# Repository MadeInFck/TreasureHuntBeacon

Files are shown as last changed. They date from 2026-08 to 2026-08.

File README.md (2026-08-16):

# Treasure Hunt — Beacon

**English** · [Français](README.fr.md)

BLE beacon specification and DIY build for the **Treasure Hunt** iOS app.

**Frame specification version 1.0.** Beacons and app releases are compatible
within the same major version.

Each hunt step can be marked by an iBeacon. The app ranges nearby beacons to
guide players over the last 30 metres, where GPS alone is too imprecise.

You have two options:

- **Buy** a commercial iBeacon and reconfigure it with the values below.
- **Build** your own from an ESP32 board — see [Build your own](#build-your-own).

---

## Beacon specification

This is the contract. Any beacon that advertises the following frame will be
recognised by the app, regardless of how it was made.

### Identifiers

| Field | Value |
|---|---|
| **UUID** | `A4C27B10-5F3E-4E2A-9D8C-1B6F0E3D7A52` |
| **MAJOR** | Hunt number, `1`–`65535` |
| **MINOR** | `(step << 8) \| battery` — see below |

The UUID is **fixed for the whole project**. It is a namespace, not a device
identifier — Apple's model is one UUID per application, with major and minor
carrying everything else. Do not change it: the app filters on this exact value
and will not see a beacon advertising anything else.

### MINOR encoding

The 16-bit minor carries two fields:

```
 15                    8 7                     0
┌───────────────────────┬───────────────────────┐
│      step (1-255)     │    battery (0-255)    │
└───────────────────────┴───────────────────────┘
```

| Byte | Meaning |
|---|---|
| High | Step number within the hunt, `1`–`255` |
| Low | Battery level, or `0x00` for "no telemetry" |

Battery byte to voltage:

```
voltage_mV = 2500 + (minor & 0xFF) * 10
```

This gives 10 mV steps from 2.50 V to 5.05 V, covering both LiPo and LiFePO4.
`0x00` would decode as 2.50 V — a cell that is already dead — so it is safe to
use as the "no telemetry" sentinel.

Commercial beacons cannot produce this telemetry. Set their minor to
`step << 8` (for example `0x0100` = 256 for step 1) and the app will show the
step with an unknown battery level.

### Radio parameters

| Parameter | Value |
|---|---|
| Advertising interval | 100 ms |
| Advertising flags | `0x04` (BR/EDR not supported) |
| Scan response | Disabled |
| TX power field | **Measured per beacon** — see [calibration](docs/calibration.md) |

The TX power byte is the RSSI an iPhone reads at exactly 1 metre. It is not a
setting you copy — a wrong value makes every distance estimate wrong. Measure it
for each unit, in its final enclosure.

### Full manufacturer data

25 bytes, following the standard `0x1A 0xFF` length and type prefix:

```
4C 00                                            Apple company ID, little-endian
02 15                                            iBeacon subtype + remaining length
A4 C2 7B 10 5F 3E 4E 2A 9D 8C 1B 6F 0E 3D 7A 52  UUID, big-endian
00 01                                            MAJOR = 1, big-endian
01 00                                            MINOR = step 1, no telemetry
C5                                               TX power = -59 dBm
```

Total advertising payload: 3 bytes of flags + 27 bytes of manufacturer data
structure = **30 of the 31 available bytes**. There is no room for a device
name. This is why the firmware calls `BLEDevice::init("")` with an empty string.

### Status LED

Boards with an RGB LED signal their identity at power-up, once:

| Signal | Meaning |
|---|---|
| 1 white flash | booting |
| N violet blinks | hunt number (MAJOR) |
| M blue blinks | step number |

Then a brief pulse every 5 s: **green** alive, **amber** battery low, **red**
battery critical. Red appears nowhere else, so a red pulse always means the
cell needs attention.

Arm the beacon, count violet, count blue, check the pulse colour, close the
box. That is the whole pre-flight check, no phone needed.

---

## Using a commercial beacon

Most commercial iBeacons are reconfigurable through their manufacturer's app.
Set:

- UUID → `A4C27B10-5F3E-4E2A-9D8C-1B6F0E3D7A52`
- Major → your hunt number
- Minor → `step << 8` (step 1 → `256`, step 2 → `512`, step 3 → `768`)
- Advertising interval → 100 ms if adjustable

**Check before buying.** Some low-cost models ship with a factory-locked UUID.
Those cannot be used. The product page must state that the UUID is
user-configurable.

---

## Build your own

| | |
|---|---|
| Firmware | [`firmware/beacon/`](firmware/beacon/) |
| Board choice and wiring | [`hardware/`](hardware/) |
| Enclosure | [`enclosure/`](enclosure/) |
| TX power calibration | [`docs/calibration.md`](docs/calibration.md) |
| Battery and autonomy | [`docs/battery.md`](docs/battery.md) |
| When nothing is detected | [`docs/troubleshooting.md`](docs/troubleshooting.md) |

Minimum to get a beacon on the air: an ESP32 board with BLE, a USB cable, and
the Arduino IDE with the ESP32 core 3.x. Battery and enclosure come later.

---

## Repository layout

```
firmware/
  beacon/          Beacon firmware — flash one per hunt step
  scanner/         Bench scanner — decodes frames, useful for validation
  vbat_probe/      Differential probe — finds a board's VBAT divider
  CONFIGURATION.md Per-beacon settings
hardware/          Boards, wiring diagrams, bill of materials
enclosure/         Parametric OpenSCAD case, ready-made STLs
docs/              Calibration, battery, troubleshooting
```

Code comments are in English only, to keep a single source of truth.
Documentation is available in English and French.

---

## Safety

This project involves lithium cells. Read the warnings in
[`hardware/README.md`](hardware/README.md) before wiring a battery. Sealed
enclosures left in direct sunlight can exceed the safe operating range of both
the board and the cell.

---

## License

MIT — see [LICENSE](LICENSE).

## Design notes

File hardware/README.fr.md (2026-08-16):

# Matériel

[English](README.md) · **Français**

## Choisir une carte

N'importe quel ESP32 doté du BLE émettra correctement. Ce qui les sépare, c'est
la quantité de circuiterie externe à ajouter pour un fonctionnement sur
batterie.

| Carte | Taille (mm) | Charge | Mesure VBAT | Antenne u.FL | Composants externes |
|---|---|---|---|---|---|
| M5Stack NanoC6 | 23,5 × 12 × 9,5 | non | non | non | 5 |
| LOLIN C3 Pico | 25,4 × 25,4 | oui | **oui**, après pontage | non | 1 |
| XIAO ESP32C3 | 21 × 17,5 | oui | non | u.FL **uniquement** | 3 |
| XIAO ESP32C6 | 21 × 17,5 | oui | non | céramique + u.FL, bascule logicielle | 3 |
| Unexpected Maker TinyC6 | 35 × 17,8 × 4,3 | oui | **oui** | choisie à l'achat | 1 |
| ESP32 classique | variable | non | non | non | à garder comme scanner de banc |

Pour un prototypage sur USB uniquement, rien de tout cela n'a d'importance :
prenez ce que vous avez. Les différences apparaissent dès l'ajout d'une
batterie.

**À propos des antennes.** Le XIAO ESP32C6 bascule entre son antenne céramique
et le connecteur u.FL à l'exécution (GPIO3 au niveau bas active le commutateur
RF, GPIO14 au niveau haut sélectionne l'externe). Le choix reste donc ouvert
après impression du boîtier. L'ESP32C3 n'a aucune antenne intégrée : l'antenne
externe fournie est obligatoire, et un u.FL qui se déboîte dégrade la portée
sans panne visible.

### Le pont à souder du LOLIN C3 Pico

Le C3 Pico **possède bien** un pont diviseur VBAT relié à GPIO3, mais WEMOS le
livre **déconnecté** pour laisser la broche libre. Rien dans la fiche produit ne
le mentionne. Un pont d'étain entre les deux pastilles au dos de la carte
l'active.

Mesuré après pontage : 2010 mV à la broche pour une cellule à 4,01 V au
multimètre — rapport de 1,995:1, donc `DIVIDER_X100 = 200` ne demande aucune
correction.

Avant pontage, GPIO1, GPIO3 et GPIO4 affichaient toutes 420 à 600 mV en
dérivant de quelques dizaines de millivolts, cellule branchée ou non : la
signature d'une entrée flottante. `firmware/vbat_probe` sert à trancher sans
supposition — il échantillonne toutes les broches ADC1 avec et sans cellule et
compare.

WEMOS emploie le même principe ailleurs : la LED d'état de charge est aussi une
empreinte non peuplée. Si une fonction semble absente sur une carte WEMOS,
cherchez des pastilles avant de conclure.

## Alimentation

Une balise ne fonctionne que le temps d'une chasse, deux ou trois heures. Un
interrupteur en série sur le fil positif de la batterie fait disparaître
entièrement la question de la consommation de veille : interrupteur ouvert, le
courant est nul, ce qu'aucun firmware ne peut égaler.

Conséquence à connaître : interrupteur ouvert, la batterie est déconnectée du
chargeur, donc **la recharge est impossible switch sur off**.

### Option A — carte avec charge et mesure VBAT (TinyC6)

```
Batterie + ── Interrupteur ── BAT
Batterie − ─────────────────  GND
```

Trois composants. Charge, régulation et pont diviseur sont déjà sur le PCB.

### Option B — carte avec charge seule (XIAO C3/C6)

```
Batterie + ── Interrupteur ──┬── BAT+
                             │
                             R1 100k
                             ├────────── A0/A1  (ADC)
                             R2 100k     └─ C1 100nF ─ GND
                             │
                            GND
Batterie − ───────────────────  BAT−
```

Six composants. Piquez le pont **après** l'interrupteur, jamais avant : placé
en amont, il tire ~18 µA en permanence et vide la cellule en quelques semaines
alors que vous croyez tout coupé.

Placez C1 physiquement contre la carte, pas près des résistances. Son rôle est
de fournir en quelques microsecondes la charge que réclame l'échantillonneur de
l'ADC ; au bout d'un fil de 15 cm, l'inductance du câble annule l'effet.

### Option C — carte avec port Grove 5 V uniquement (NanoC6)

```
Batterie ── TP4056 ── Interrupteur ──┬── Boost MT3608 5V ── Grove 5V
(avec protection)                    │
                                     └── Pont R1/R2/C1 ──── Grove G1
                                                            Grove GND
```

Huit composants. Le boost n'existe que parce que le port Grove fournit du 5 V :
une LiPo à 3,7 V ne peut pas traverser un LDO et ressortir régulée à 3,3 V au
fil de sa décharge. Il en découle aussi une mesure batterie plus bruitée qu'en
option A ou B, pour des raisons purement topologiques.

**Couleurs des fils Grove :** noir GND, rouge 5 V, blanc G1, jaune G2.

## Nomenclature — option B

| Rep. | Composant | Remarque |
|---|---|---|
| BT1 | LiPo 1S, 500–1000 mAh | JST PH 2.0 |
| SW1 | Interrupteur à glissière SPST | sur le fil positif |
| R1, R2 | 100 kΩ 1 % | 0,25 W |
| C1 | 100 nF céramique | au plus près de la broche ADC |

## Avertissements

**Cellules lithium.** Un chargeur intégré est un chargeur LiPo, à tension
constante de 4,2 V. Une cellule LiFePO4 se charge à 3,6 V : la brancher sur un
chargeur LiPo revient à la surcharger. Si vous voulez la recharge par USB-C,
utilisez une LiPo.

**Réglez un MT3608 à 5,0 V avant de le connecter.** Ces modules sortent d'usine
avec le potentiomètre dans une position arbitraire et peuvent délivrer plus de
20 V. Alimentez-le seul, mesurez, ajustez, puis reliez-le à la carte.

**Utilisez un TP4056 avec protection.** Les modules nus n'exposent que B+/B−
sans coupure basse tension. Une LiPo descendue sous 2,5 V est bonne à jeter.

**Température.** Le NanoC6 est donné pour 0–40 °C. Un boîtier sombre et étanche
en plein soleil dépasse cette plage sans difficulté. Imprimez en filament clair,
placez les caches à l'ombre, et considérez une LiPo qui gonfle dans une boîte
fermée comme un sujet de sécurité, pas de longévité.

## Notes sur le boîtier

**Les tags NFC et le métal ne font pas bon ménage.** Un NTAG213 fonctionne par
couplage inductif à 13,56 MHz. Une poche LiPo ou un plan de masse de PCB juste
derrière désaccorde l'antenne et annule souvent complètement la portée de
lecture. Prévoyez 8 à 10 mm d'air entre le tag et l'électronique, sur une face
opposée à la cellule, ou utilisez un tag « on-metal » à couche de ferrite.

**Dégagement d'antenne.** Laissez 10 à 15 mm libres autour de l'extrémité
antenne du module, 1,5 mm d'épaisseur de paroi maximum devant, et aucun câblage
qui la traverse. Une antenne céramique est plus sensible au diélectrique proche
qu'une antenne gravée sur PCB.

**Hauteur de pose.** Le 2,4 GHz est absorbé par l'eau, donc par le sol, la roche
humide et le maquis. Une balise posée au sol est reçue beaucoup plus faiblement
et son estimation de distance devient erratique. Visez 30 à 50 cm de hauteur, et
calibrez à la hauteur d'usage réelle.

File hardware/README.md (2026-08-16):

# Hardware

**English** · [Français](README.fr.md)

## Choosing a board

Any ESP32 with BLE will advertise correctly. What separates them is how much
external circuitry you have to add for battery operation.

| Board | Size (mm) | Charging | VBAT sense | u.FL antenna | External parts |
|---|---|---|---|---|---|
| M5Stack NanoC6 | 23.5 × 12 × 9.5 | no | no | no | 5 |
| LOLIN C3 Pico | 25.4 × 25.4 | yes | **yes**, once bridged | no | 1 |
| XIAO ESP32C3 | 21 × 17.5 | yes | no | **only** u.FL | 3 |
| XIAO ESP32C6 | 21 × 17.5 | yes | no | ceramic + u.FL, software switch | 3 |
| Unexpected Maker TinyC6 | 35 × 17.8 × 4.3 | yes | **yes** | chosen at purchase | 1 |
| ESP32 classic | varies | no | no | no | best kept as the bench scanner |

If you are prototyping on USB only, none of this matters — pick whatever you
have. The differences appear the moment you add a battery.

**On antennas.** The XIAO ESP32C6 selects between its ceramic antenna and the
u.FL connector at runtime (GPIO3 low enables the RF switch, GPIO14 high selects
external). That keeps the choice open after the enclosure is printed. The
ESP32C3 has no on-board antenna at all: the supplied external antenna is
mandatory, and a u.FL connector that works loose degrades range silently
without an obvious failure.

### The LOLIN C3 Pico solder bridge

The C3 Pico **does** have a VBAT divider feeding GPIO3, but WEMOS ships it
**disconnected** so the pin stays free for other uses. Nothing in the feature
list mentions it. Bridge the two pads on the underside of the board and the
divider comes alive.

Measured after bridging: 2010 mV at the pin for a cell reading 4.01 V on a
multimeter — a 1.995:1 ratio, so `DIVIDER_X100 = 200` needs no correction.

Before bridging, GPIO1, GPIO3 and GPIO4 all read 420–600 mV and wandered by
tens of millivolts, cell connected or not: the signature of a floating input.
`firmware/vbat_probe` exists to make that call without guesswork — it samples
every ADC1 pin with and without the cell and reports the difference.

WEMOS uses the same pattern elsewhere: the charge status LED is also an
unpopulated footprint. If a feature seems missing on a WEMOS board, look for
pads before concluding it is absent.

## Power

A beacon only needs to run for the duration of a hunt — two or three hours.
Put a switch in series with the battery positive lead and quiescent current
stops being a design concern entirely: an open switch draws nothing, which no
firmware can beat.

Consequence worth knowing: with the switch open, the battery is disconnected
from the charger, so **you cannot charge with the switch off**.

### Option A — board with charging and VBAT sense (TinyC6)

```
Battery + ── Switch ── BAT
Battery − ─────────── GND
```

Three components. Charging, regulation and the divider are already on the PCB.

### Option B — board with charging only (XIAO C3/C6)

```
Battery + ── Switch ──┬── BAT+
                      │
                      R1 100k
                      ├────────── A0/A1  (ADC)
                      R2 100k     └─ C1 100nF ─ GND
                      │
                     GND
Battery − ─────────────── BAT−
```

Six components. Tap the divider **after** the switch, never before, or it
draws ~18 µA continuously and drains the cell over weeks while you believe
everything is off.

Place C1 physically against the board, not near the resistors. Its job is to
supply the charge the ADC sample-and-hold demands within microseconds; at the
end of a 15 cm wire, cable inductance cancels the effect.

### Option C — board with a 5 V-only Grove port (NanoC6)

```
Battery ── TP4056 ── Switch ──┬── MT3608 boost 5V ── Grove 5V
(with protection)             │
                              └── R1/R2/C1 divider ── Grove G1
                                                      Grove GND
```

Eight components. The boost exists only because the Grove port supplies 5 V:
a LiPo at 3.7 V cannot pass through an LDO and come out regulated at 3.3 V as
it discharges. This also means a noisier battery reading than option A or B,
for purely topological reasons.

**Grove wire colours:** black GND, red 5 V, white G1, yellow G2.

## Bill of materials — option B

| Ref | Part | Note |
|---|---|---|
| BT1 | 1S LiPo, 500–1000 mAh | JST PH 2.0 |
| SW1 | SPST slide switch | on the positive lead |
| R1, R2 | 100 kΩ 1% | 0.25 W |
| C1 | 100 nF ceramic | as close to the ADC pin as possible |

## Warnings

**Lithium cells.** An on-board charger is a LiPo charger, constant-voltage at
4.2 V. A LiFePO4 cell charges at 3.6 V — putting one on a LiPo charger
overcharges it. If you want USB-C charging, use LiPo.

**Set an MT3608 to 5.0 V before connecting it.** These modules ship with the
trimmer in an arbitrary position and can output over 20 V. Power it alone,
measure, adjust, then wire it to the board.

**Use a TP4056 module with protection.** Bare modules expose only B+/B− with no
low-voltage cutoff. A LiPo taken below 2.5 V is scrap.

**Temperature.** The NanoC6 is rated 0–40 °C. A dark sealed enclosure in direct
sun exceeds that easily. Print in a light filament, place caches in shade, and
treat a swelling LiPo in a closed box as a safety matter, not a longevity one.

## Enclosure notes

**NFC tags and metal do not mix.** An NTAG213 works by inductive coupling at
13.56 MHz. A LiPo pouch or a PCB ground plane directly behind it detunes the
antenna and often kills read range completely. Design an 8–10 mm air gap
between the tag and the electronics, on a face away from the cell, or use an
"on-metal" tag with a ferrite layer.

**Antenna keep-out.** Leave 10–15 mm clear around the module's antenna end,
1.5 mm maximum wall thickness in front of it, and no wiring crossing it. A
ceramic antenna is more sensitive to nearby dielectric than a PCB trace.

**Mounting height.** 2.4 GHz is absorbed by water, so by soil, wet rock and
vegetation. A beacon lying on the ground reads much weaker and its distance
estimate becomes erratic. Aim for 30–50 cm above ground, and calibrate at the
height you will actually use.

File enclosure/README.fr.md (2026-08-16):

# Boîtier

[English](README.md) · **Français**

Boîtier étanche paramétrique pour une balise, en OpenSCAD. Ouvrez
`enclosure.scad`, réglez `part`, F6, exportez le STL. Les STL prêts à trancher
sont dans `stl/`.

## L'idée de conception

Le boîtier **ne comporte aucune traversée de paroi**. La LED se lit à travers
une zone amincie, l'interrupteur et l'USB-C restent à l'intérieur, et on ouvre
la boîte pour recharger. Le plan de joint du couvercle est donc le seul point à
étancher.

Un trou pour une LED d'état ou une prise de charge, c'est en général ce qui
fait fuir un boîtier imprimé. Ne pas en faire supprime le problème au lieu de
le résoudre.

## Dimensions

Les valeurs par défaut correspondent à une cellule de 4000 mAh mesurée à
65 × 40 × 12 mm et à une carte LOLIN C3 Pico.

| | |
|---|---|
| Encombrement | 101 × 76 × 35 mm |
| Cavité | 69 × 44 × 29 mm |

C'est volumineux, et la batterie en est la cause : la cellule impose la cavité,
le rebord d'étanchéité ajoute 14 mm, les oreilles de vissage 18 de plus. Une
cellule de 1000 mAh en 35 × 25 mm ramène l'ensemble autour de 70 × 60 mm — il
suffit de changer `bat_x`, `bat_y` et `bat_z`, tout le reste se recalcule.

**Mesurez votre cellule au pied à coulisse, connecteur JST et gaine
thermorétractable compris.** Ce faisceau dépasse souvent la poche de 2 à 3 mm
et c'est lui le vrai point haut.

## Ce que le modèle contient

- Gorge de joint de 2,5 × 1,8 mm, tout autour du rebord
- Quatre inserts M3 thermofusibles dans des bossages d'angle, reliés à la coque
- Lamages pour vis à tête cylindrique dans le couvercle
- Fenêtre LED : poche borgne prise par l'intérieur, laissant 0,6 mm de paroi
- Logette du tag NFC, sur la face externe par défaut (`nfc_inside = true` la
  bascule à l'intérieur et ajoute un cercle gravé marquant le point de tap)
- Berceau dans lequel le C3 Pico se pose — sans vis, donc sans avoir à deviner
  l'entraxe de perçage de la carte. Une mousse sous le couvercle la maintient.
- Nervures basses empêchant la cellule de glisser

## Joint

Coulez-le en place plutôt que d'acheter un O-ring. Remplissez la gorge de
silicone **neutre** (surtout pas acétique : l'acide acétique attaque le cuivre
et les soudures), enduisez la face du couvercle de vaseline comme agent de
démoulage, refermez, laissez 24 heures. Vous obtenez un joint moulé sur vos
propres tolérances d'impression, bien plus tolérant qu'un O-ring sur une gorge
imprimée en FDM où quelques dixièmes de dérive suffisent à créer une fuite.

## Impression

Les deux pièces face ouverte vers le bas, sans support. Le couvercle se pose
sur sa face externe, ergot vers le haut.

L'étanchéité vient de l'adhésion inter-couches, pas du joint :

- **5 périmètres** minimum, couches de 0,15 mm
- Température d'extrusion en haut de la plage recommandée, ventilation réduite
- Filament blanc ou naturel — une boîte sombre en plein soleil dépasse ce que
  le PLA tolère, et le blanc diffuse la LED bien mieux que le transparent, qui
  s'imprime laiteux et strié

Le PETG vaut mieux que le PLA si vous en avez : il ramollit vers 80 °C au lieu
de 60.

## Avant d'imprimer la pièce complète

Imprimez d'abord un **gabarit de rebord** — seulement les 5 mm supérieurs du
corps. Dix minutes, et vous saurez si `lip_gap` (0,35 mm par défaut) convient à
votre machine et si la gorge sort proprement. Trop serré, le couvercle ne
s'emboîte pas ; trop lâche, il vagabonde pendant le vissage.

## Points ouverts

L'interrupteur n'a pas encore de logement. Il reste 12 mm de hauteur libre
entre la carte et le couvercle, mais il flotte au bout de ses fils. À ajouter
une fois le modèle choisi.

L'orientation de l'antenne céramique dépend du bord du C3 Pico qui la porte. Le
berceau place la carte contre la paroi droite — vérifiez votre carte et inversez
le signe dans `board_tray()` si l'antenne se retrouve tournée vers l'intérieur
et vers la batterie.

## Respiration thermique

Une boîte totalement close qui passe de 20 à 55 °C au soleil voit sa pression
interne monter d'environ 12 %. En refroidissant la nuit, elle crée une
dépression qui aspire l'eau à travers le joint. C'est le mode de défaillance
classique des boîtiers étanches laissés dehors.

Sans objet pour une cache posée quelques heures. Si vous en laissez une
plusieurs jours, ajoutez une pastille d'équilibrage Gore-Tex collée à
l'intérieur sur un petit trou.

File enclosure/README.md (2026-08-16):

# Enclosure

**English** · [Français](README.fr.md)

Parametric sealed case for a beacon, in OpenSCAD. Open `enclosure.scad`, set
`part`, press F6, export STL. Ready-made STLs are in `stl/`.

## The design idea

The case has **no wall penetrations**. The LED reads through a thinned window,
the switch and USB-C stay inside, and you open the box to charge. The lid joint
is therefore the only thing that needs to seal.

A hole for a status LED or a charging port is what usually makes a printed
enclosure leak. Not making one removes the problem instead of solving it.

## Dimensions

Defaults are sized for a 4000 mAh cell measured at 65 × 40 × 12 mm and a LOLIN
C3 Pico.

| | |
|---|---|
| Envelope | 101 × 76 × 35 mm |
| Cavity | 69 × 44 × 29 mm |

That is a large box, and the battery is why: the cell fixes the cavity, the
sealing rim adds 14 mm, the screw ears another 18. A 1000 mAh cell at
35 × 25 mm brings it down to roughly 70 × 60 mm — change `bat_x`, `bat_y` and
`bat_z` and everything else recalculates.

**Measure your cell with calipers, including the JST connector and its heat
shrink.** That bundle is often 2–3 mm taller than the pouch and it is the real
high point.

## Features

- Gasket groove, 2.5 × 1.8 mm, running around the rim
- Four M3 heat-set inserts in corner bosses, hulled into the shell
- Counterbored screw holes in the lid
- LED window: a blind pocket taken from the inside, leaving 0.6 mm of wall
- NFC tag pocket, on the outer face by default (`nfc_inside = true` moves it
  inside and adds an engraved ring to mark the tap point)
- Board cradle the C3 Pico drops into — no screws, so no need to guess the
  board's hole pattern. A foam pad under the lid holds it down.
- Low ribs stop the cell sliding

## Gasket

Cast it in place rather than buying an O-ring. Fill the groove with **neutral
cure** silicone (not acetic — acetic acid attacks copper and solder joints),
smear the lid face with petroleum jelly as a release agent, close, and leave it
24 hours. You get a gasket moulded to your own print tolerances, which is far
more forgiving than an O-ring on an FDM groove where a few tenths of drift
cause a leak.

## Printing

Both parts open face down, no supports. The lid prints on its outer face with
the spigot pointing up.

Watertightness comes from layer adhesion, not from the gasket:

- **5 perimeters** minimum, 0.15 mm layers
- Extrusion temperature at the top of the recommended range, reduced cooling
- White or natural filament — a dark box in direct sun exceeds what PLA
  tolerates, and white diffuses the LED far better than clear filament, which
  prints milky and streaked

PETG is better than PLA if you have it: it softens near 80 °C instead of 60.

## Before printing the full part

Print a **test rim** first — just the top 5 mm of the body. Ten minutes, and it
tells you whether `lip_gap` (0.35 mm by default) suits your machine and whether
the groove came out clean. Too tight and the lid will not seat; too loose and
it wanders while you tighten the screws.

## Still open

The switch has no dedicated housing yet. There is 12 mm of clear height between
the board and the lid, but it currently floats on its wires. Add a cradle once
you have chosen the part.

The ceramic antenna orientation depends on which edge of the C3 Pico carries
it. The cradle places the board against the right-hand wall — check your board
and flip the sign in `board_tray()` if the antenna ends up pointing inward at
the battery.

## Thermal breathing

A fully sealed box going from 20 to 55 °C in the sun sees its internal pressure
rise about 12 %. Cooling overnight creates a partial vacuum that draws water
past the gasket. This is the classic failure mode of sealed outdoor cases.

Irrelevant for a cache placed for a few hours. If you ever leave one out for
days, add a Gore-Tex vent patch over a small hole on the inside face.

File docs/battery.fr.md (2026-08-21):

# Batterie

[English](battery.md) · **Français**

## Cellule testée

4000 mAh, 1S, 3C, 3,7 V nominal, 14,8 Wh. LOLIN C3 Pico, advertising à 100 ms,
battement RGB, 26 °C ambiants, aucune charge en dehors de la balise elle-même.

## Courbe de décharge complète

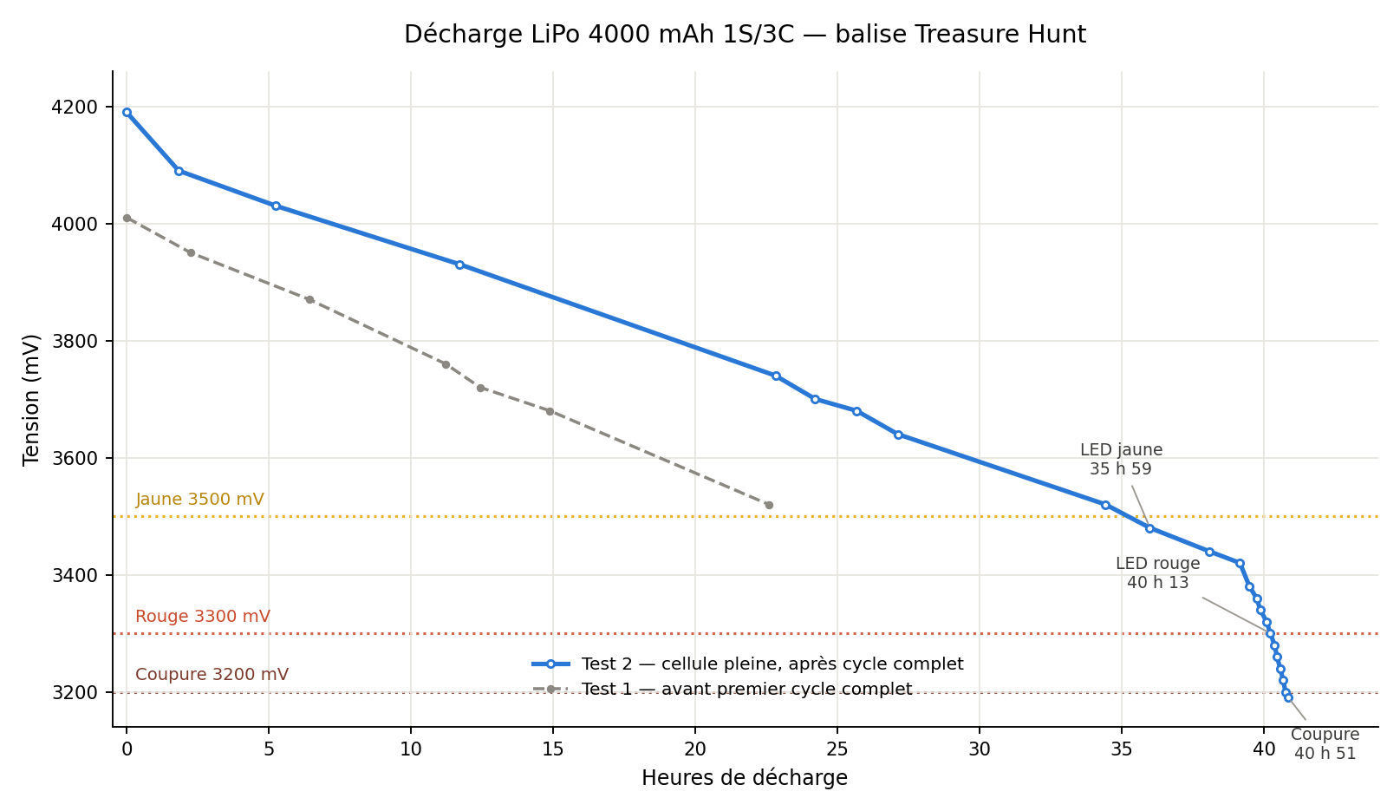
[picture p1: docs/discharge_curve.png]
Courbe de décharge


Deux passages sur la même cellule. Le test 1 était sa toute première décharge
après achat ; le test 2 a suivi un cycle complet de charge/décharge. L'écart de
52 % entre les deux est le résultat marquant — **dimensionnez sur le chiffre du
premier cycle si vous ne pouvez mesurer qu'une fois**, c'est le cas le plus
défavorable.

## Chronologie, test 2

| Écoulé | Tension | Événement |
|---|---|---|
| 0 | 4190 mV | charge pleine |
| 5 h 15 | 4030 mV | fin de la phase raide initiale, entrée en régime linéaire (~18 mV/h) |
| 35 h 59 | 3480 mV | **LED passe au jaune** — `BAT_LOW_MV` (3500 mV) |
| ~39 h 29 | ~3380 mV | coude de décharge — la pente passe de ~18 à ~140 mV/h |
| 40 h 13 | 3300 mV | **LED passe au rouge** — `BAT_CRIT_MV` (3300 mV) |
| 40 h 45 | 3200 mV | seuil de coupure franchi |
| 40 h 51 | ~3190 mV | **trois flashs rouges lents, deep sleep** — `BAT_CUTOFF_MV` |

Six minutes entre le franchissement du seuil de coupure et l'arrêt effectif :
le firmware exige trois relevés bas consécutifs, à une minute d'intervalle,
avant d'agir — voir [dépannage](troubleshooting.fr.md) pour la raison.

## Comment lire cette courbe

**Le régime linéaire occupe presque toute la décharge.** Sur le graphique en
largeur complète il paraît plat ; l'essentiel du comportement intéressant — le
coude, les deux changements de couleur de LED, la coupure — tient dans les
90 dernières minutes. Si vous ne prenez qu'une mesure pendant une chasse,
attendez-vous à tomber dans ce long plateau.

**Les segments de moins de six heures environ ne sont pas fiables**, près du
régime linéaire : les 10 mV de quantification de l'ADC dominent la lecture à
cette échelle. Dans ces données, deux segments courts consécutifs ont donné
28,6 et 13,8 mV/h ; combinés ils font 21,0, ce qui rejoint le régime de part et
d'autre. Fiez-vous aux fenêtres de plusieurs heures, pas à un segment isolé —
cela a coûté du temps réel pendant le test, avec un « coude » annoncé deux fois
sur des segments courts avant que le vrai n'apparaisse sur une fenêtre de six
heures.

**Ne convertissez pas la tension en pourcentage.** La relation n'est pas
linéaire et dépend de la cellule, de son âge et de sa chimie — c'est toute la
raison pour laquelle la balise émet des millivolts plutôt qu'un pourcentage
calculé. Le chiffre utile n'est pas « combien reste-t-il » mais **combien de
temps avant le prochain changement de couleur**, et c'est ce que donne ce
tableau.

## Dimensionnement

À environ 40 heures jusqu'à la coupure, une cellule de 4000 mAh couvre une
douzaine de chasses de trois heures. Le C3 Pico charge à 500 mA, donc recharger
une cellule de cette taille à vide demande plus de huit heures.

Une cellule de 1000 mAh couvre encore plusieurs chasses, se recharge en moins
de deux heures et occupe le quart du volume — ce qui compte beaucoup dès qu'on
dessine un boîtier destiné à se cacher sous un rocher. Voir
[matériel](../hardware/README.fr.md) pour l'arbitrage LiPo contre LiFePO4.

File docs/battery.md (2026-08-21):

# Battery

**English** · [Français](battery.fr.md)

## Test cell

4000 mAh, 1S, 3C, 3.7 V nominal, 14.8 Wh. LOLIN C3 Pico, advertising at
100 ms, RGB heartbeat, 26 °C ambient, no load beyond the beacon itself.

## Full discharge curve

Discharge curve

Two runs on the same cell. Test 1 was its first discharge after purchase;
test 2 followed a full charge/discharge cycle. The 52% gap between them is
the headline result — **size for the first-cycle number if you can only
measure once**, since that is the worst case.

## Timeline, test 2

| Elapsed | Voltage | Event |
|---|---|---|
| 0 | 4190 mV | full charge |
| 5 h 15 | 4030 mV | steep initial phase ends, linear regime begins (~18 mV/h) |
| 35 h 59 | 3480 mV | **LED turns yellow** — `BAT_LOW_MV` (3500 mV) |
| ~39 h 29 | ~3380 mV | discharge knee — rate jumps from ~18 to ~140 mV/h |
| 40 h 13 | 3300 mV | **LED turns red** — `BAT_CRIT_MV` (3300 mV) |
| 40 h 45 | 3200 mV | cutoff threshold crossed |
| 40 h 51 | ~3190 mV | **three slow red flashes, deep sleep** — `BAT_CUTOFF_MV` |

Six minutes between crossing the cutoff threshold and the actual shutdown:
the firmware requires three consecutive low readings, one minute apart,
before it acts — see [troubleshooting](troubleshooting.md) for why.

## Reading this curve

**The linear regime is almost the whole discharge.** On the full-width plot it
looks flat; essentially all of the interesting behaviour — the knee, both LED
colour changes, the cutoff — happens in the last 90 minutes. If you only take
one measurement during a hunt, expect it to land in that long flat middle.

**Segments under about six hours are not reliable**, close to the linear
regime: 10 mV of ADC quantisation dominates the reading at that timescale. In
this data, two consecutive short segments read 28.6 and 13.8 mV/h; combined
they average 21.0, matching the regime either side of them. Trust multi-hour
windows, not single short ones — this cost real time during the test, with
a "knee" announced twice on short segments before the real one showed up
on a six-hour window.

**Do not convert voltage to a percentage.** The relationship is non-linear and
depends on the cell, its age and its chemistry — the whole reason the beacon
advertises millivolts rather than a computed percentage. The useful number is
not "how full is it" but **how long until the next LED colour**, and that is
what this table gives you.

## Sizing

At roughly 40 hours to cutoff, a 4000 mAh cell covers something like a dozen
three-hour hunts. The C3 Pico charges at 500 mA, so refilling an empty cell of
that size takes over eight hours.

A 1000 mAh cell still covers several hunts, recharges in under two hours, and
takes a quarter of the volume — which matters once you are designing an
enclosure meant to hide under a rock. See [hardware](../hardware/README.md)
for the LiPo vs LiFePO4 trade-off.

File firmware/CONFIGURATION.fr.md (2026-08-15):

# Configuration

[English](CONFIGURATION.md) · **Français**

Tout ce qui se modifie se trouve en tête de `beacon/beacon.ino`.

## Réglages propres à chaque balise

| Constante | Signification |
|---|---|
| `STEP_ID` | Numéro d'étape, octet haut du MINOR. **À changer pour chaque balise.** |
| `HUNT_ID` | Numéro de chasse, MAJOR. Identique pour toutes les balises d'une chasse. |
| `TX_POWER_1M` | RSSI à 1 m. **À mesurer par exemplaire** — voir [calibration](../docs/calibration.fr.md). |

Flashez le même fichier une fois par étape, en ne changeant que `STEP_ID`.

Étiquetez physiquement chaque carte au moment du flash. Deux cartes identiques
sont impossibles à distinguer ensuite, et un RSSI attribué à la mauvaise balise
fausse toute la comparaison.

## Fonctions optionnelles

| Drapeau | Défaut | Nécessite |
|---|---|---|
| `ENABLE_BATTERY_TELEMETRY` | `0` | Un pont diviseur — voir [matériel](../hardware/README.fr.md) |
| `ENABLE_STATUS_LED` | `1` | Une LED sur la carte |

Télémétrie désactivée, l'octet bas du MINOR vaut `0x00`, ce que la
spécification définit comme « pas de télémétrie ». Ne l'activez qu'une fois le
pont diviseur câblé, sinon l'application affichera un niveau de batterie faux.

## Broche ADC pour la télémétrie batterie

Réglez `BAT_ADC_PIN` sur une broche de l'**ADC1**. L'ADC2 est inutilisable
pendant que la radio fonctionne sur plusieurs variantes d'ESP32.

| Carte | Broche conseillée | Remarque |
|---|---|---|
| M5Stack NanoC6 | `1` | Fil blanc du Grove ; seuls G1 et G2 sont exposés |
| XIAO ESP32C6 | `0` (A0) | GPIO3 et GPIO14 réservés au commutateur RF |
| XIAO ESP32C3 | `3` (A1) | **Évitez A0/GPIO2**, broche de strapping |
| ESP32 classique | `32`–`39` | Plage ADC1 |

Calibrez `BAT_CAL` une fois par carte : mesurez la tension réelle de la cellule
au multimètre, divisez par ce qu'affiche la console série, écrivez le quotient.
Deux résistances à 1 % introduisent à elles seules jusqu'à 2 % d'erreur.

## LED de statut

`LED_BUILTIN` est définie par le core pour les cartes reconnues. Si la LED reste
éteinte, vérifiez le brochage de votre carte et indiquez le numéro
explicitement. Si elle reste allumée et clignote en s'éteignant, passez
`LED_ACTIVE_HIGH` à `0`.

Retirez ou désactivez la LED avant de dissimuler une balise en extérieur. Une
boîte qui clignote sous un rocher est un indice que vous n'aviez pas prévu de
donner.

## IDE Arduino

- Core ESP32 **3.x** requis pour les cibles C6 et H2
- Sélectionnez la carte exacte dans le menu Outils
- Moniteur série à **115200**
- Sur les cartes en USB natif, le port disparaît et se recrée à chaque reset ;
  double appui sur RESET pour forcer le bootloader s'il n'apparaît pas

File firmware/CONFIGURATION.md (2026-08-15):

# Configuration

**English** · [Français](CONFIGURATION.fr.md)

Everything you change lives at the top of `beacon/beacon.ino`.

## Per-beacon settings

| Constant | Meaning |
|---|---|
| `STEP_ID` | Step number, high byte of MINOR. **Change for each beacon.** |
| `HUNT_ID` | Hunt number, MAJOR. Same across all beacons of one hunt. |
| `TX_POWER_1M` | RSSI at 1 m. **Measure per unit** — see [calibration](../docs/calibration.md). |

Flash the same file once per step, changing only `STEP_ID`.

Label each board physically as you flash it. Two identical boards are
impossible to tell apart afterwards, and an RSSI attributed to the wrong
beacon invalidates the whole comparison.

## Optional features

| Flag | Default | Requires |
|---|---|---|
| `ENABLE_BATTERY_TELEMETRY` | `0` | A voltage divider — see [hardware](../hardware/README.md) |
| `ENABLE_STATUS_LED` | `1` | An on-board LED |

With telemetry off, the low byte of MINOR is `0x00`, which the specification
defines as "no telemetry". Turn it on only once the divider is wired, or the
app will display a false battery level.

## ADC pin for battery telemetry

Set `BAT_ADC_PIN` to a pin on **ADC1**. ADC2 is unusable while the radio is
active on several ESP32 variants.

| Board | Suggested pin | Note |
|---|---|---|
| M5Stack NanoC6 | `1` | Grove white wire; only G1 and G2 are exposed |
| XIAO ESP32C6 | `0` (A0) | GPIO3 and GPIO14 are reserved for the RF switch |
| XIAO ESP32C3 | `3` (A1) | **Avoid A0/GPIO2**, it is a strapping pin |
| ESP32 classic | `32`–`39` | ADC1 range |

Calibrate `BAT_CAL` once per board: measure the real cell voltage with a
multimeter, divide by what the serial console prints, write the quotient.
1% resistors alone introduce up to 2% error.

## Status LED

`LED_BUILTIN` is defined by the core for recognised boards. If the LED stays
dark, check your board's pinout and set the number explicitly. If it stays lit
and blinks off instead, set `LED_ACTIVE_HIGH` to `0`.

Remove or disable the LED before hiding a beacon outdoors. A blinking box under
a rock is a clue you did not intend to give.

## Arduino IDE

- ESP32 core **3.x** required for C6 and H2 targets
- Select the exact board in the Tools menu
- Serial monitor at **115200**
- On native-USB boards the port disappears and reappears at each reset;
  double-press RESET to force the bootloader if it does not show up

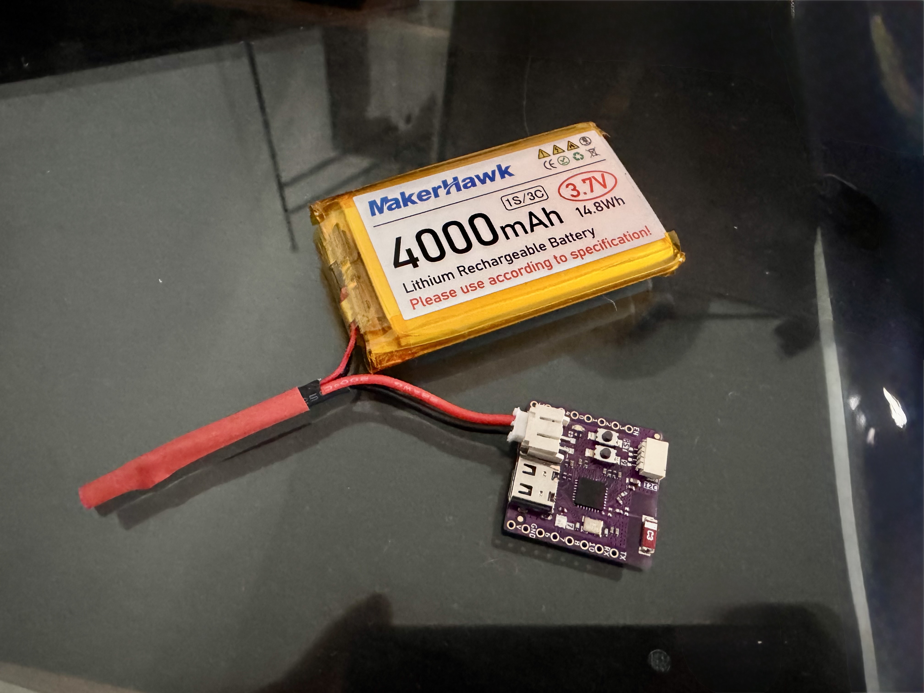
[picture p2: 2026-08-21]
hardware/Beacon_LolinC3Pico.jpeg

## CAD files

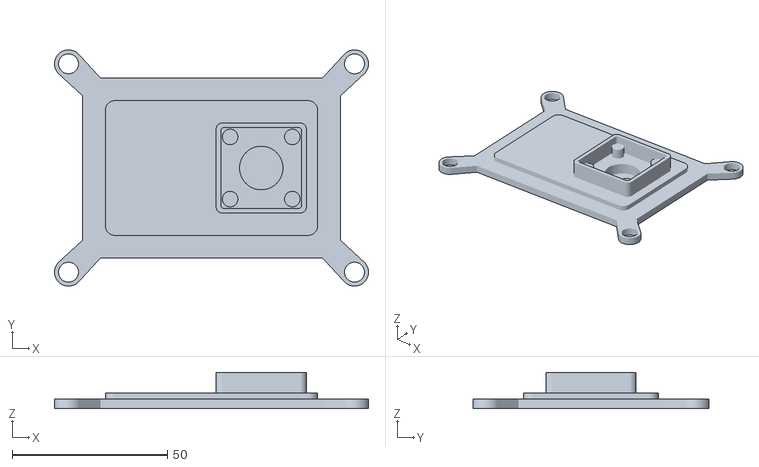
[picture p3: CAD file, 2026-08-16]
enclosure/stl/lid.stl
101.0 x 76.0 x 11.6

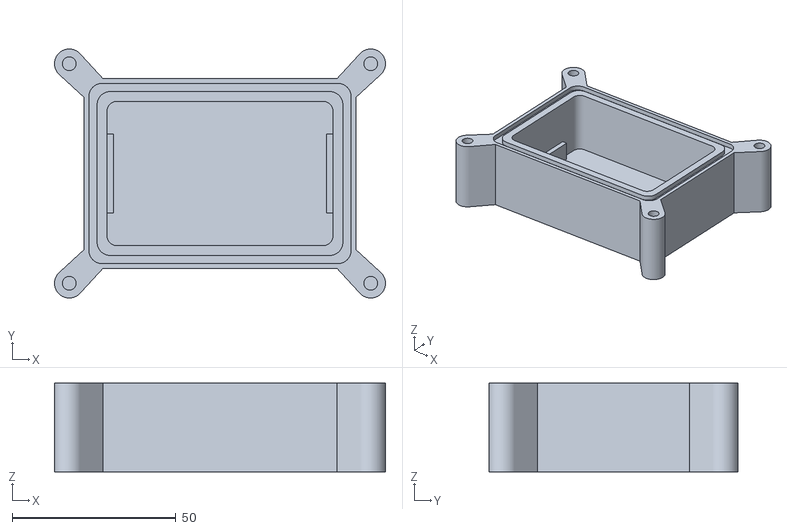
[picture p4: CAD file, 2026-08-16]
enclosure/stl/body.stl
101.0 x 76.0 x 27.1

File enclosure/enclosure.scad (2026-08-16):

// =====================================================================
//  Treasure Hunt - Beacon enclosure
//  https://github.com/MadeInFck/TreasureHuntBeacon
//
//  Sealed 3D-printed case for a LOLIN C3 Pico beacon.
//  No wall penetrations: the LED reads through a thinned window, the
//  switch and USB-C stay inside. The only seal is the lid joint.
//
//  RENDER: set part = "body" or "lid" below, F6, export STL.
//  Print both with the open face down, no supports.
//
//  Sized for a 4000 mAh cell measured at 65 x 40 x 12 mm.
// =====================================================================

part = "body";          // "body", "lid", or "both" for a preview

/* [Components] */
bat_x       = 65;       // battery length
bat_y       = 40;       // battery width
bat_z       = 12;       // battery thickness -- measured with calipers
board_x     = 25.4;     // LOLIN C3 Pico
board_y     = 25.4;
board_z     = 6;        // board + tallest component
clearance   = 2;        // around the battery

/* [Shell] */
wall        = 3;        // side and floor thickness
lid_t       = 3;        // lid plate thickness
rim         = 7;        // sealing rim width, holds the groove
corner_r    = 4;        // outer corner radius

/* [Gasket] */
groove_in   = 3.0;      // groove inner edge, from cavity wall
groove_w    = 2.5;      // groove width -- fill with neutral silicone
groove_d    = 1.8;      // groove depth

/* [Fasteners] */
boss_d      = 9;        // corner boss diameter
insert_d    = 4.2;      // M3 heat-set insert hole
insert_h    = 6;        // insert depth
screw_d     = 3.4;      // M3 clearance in the lid
head_d      = 6.4;      // socket head counterbore
head_h      = 3.2;

/* [Features] */
window_d    = 12;       // LED window diameter
window_t    = 0.6;      // remaining wall -- diffuses a WS2812 nicely
window_off  = 22;       // window centre, X from middle
nfc_d       = 27;       // NFC tag pocket (NTAG213 25 mm sticker)
nfc_t       = 0.8;      // pocket depth
nfc_off     = -22;      // tag centre, X from middle -- opposite the window
nfc_inside  = false;    // false: pocket on the outer face, tag visible and
                        //        replaceable, but exposed to rain, UV and
                        //        curious children.
                        // true:  pocket on the inner face, tag protected and
                        //        unpeelable; 13.56 MHz reads through PLA.
                        //        An engraved ring marks the tap point.
                        // Either way the LID is the right face: it is the
                        // only one with real clearance to the cell. A side
                        // or underside tag would sit 3 to 5 mm from the
                        // pouch foil and be detuned.
mark_d      = 24;       // engraved ring on the outer face, shows where to tap
mark_w      = 1.6;
mark_t      = 0.5;
lip_h       = 2;        // lid spigot, aligns the parts
lip_gap     = 0.35;     // print clearance on the spigot

/* [Derived] */
cav_x       = bat_x + 2*clearance;
cav_y       = bat_y + 2*clearance;
stand_h     = bat_z + 3;                      // board sits above the cell
cav_z       = stand_h + 4 + board_z + 4;      // + LED headroom
out_x       = cav_x + 2*rim;
out_y       = cav_y + 2*rim;
boss_x      = cav_x/2 + rim + boss_d/2;
boss_y      = cav_y/2 + rim + boss_d/2;
env_x       = 2*(boss_x + boss_d/2);
env_y       = 2*(boss_y + boss_d/2);

$fn = 64;

// ---------------------------------------------------------------------
module rrect(x, y, z, r) {
  hull() for (i = [-1, 1], j = [-1, 1])
    translate([i*(x/2 - r), j*(y/2 - r), 0])
      cylinder(h = z, r = r);
}

// Each boss is hulled back to the shell's rounded corner, otherwise the
// corner radius leaves it floating in space, tangent at best.
module bosses(h) {
  for (i = [-1, 1], j = [-1, 1])
    hull() {
      translate([i*boss_x, j*boss_y, 0]) cylinder(h = h, d = boss_d);
      translate([i*(out_x/2 - corner_r), j*(out_y/2 - corner_r), 0])
        cylinder(h = h, r = corner_r);
    }
}

module groove_cut() {
  difference() {
    rrect(cav_x + 2*(groove_in + groove_w), cav_y + 2*(groove_in + groove_w),
          groove_d + 1, corner_r);
    translate([0, 0, -0.5])
      rrect(cav_x + 2*groove_in, cav_y + 2*groove_in,
            groove_d + 2, corner_r);
  }
}

// Tray the board drops into. Avoids guessing the board's hole pattern:
// the lid presses it down through a foam pad.
module board_tray() {
  bx = board_x + 0.6;
  by = board_y + 0.6;
  translate([cav_x/2 - bx/2 - 4, 0, wall]) {
    for (i = [-1, 1], j = [-1, 1])
      translate([i*(bx/2 - 2), j*(by/2 - 2), 0]) cylinder(h = stand_h, d = 5);
    translate([0, 0, stand_h])
      difference() {
        rrect(bx + 4, by + 4, 3, 2);
        translate([0, 0, 1]) rrect(bx, by, 3, 1);
      }
  }
}

// Low ribs that stop the cell sliding without gripping it.
module battery_stops() {
  for (i = [-1, 1])
    translate([i*(bat_x/2 + 1), 0, wall])
      cube([2, bat_y*0.6, bat_z*0.7], center = true);
}

// ---------------------------------------------------------------------
module body() {
  h = wall + cav_z;
  difference() {
    union() {
      rrect(out_x, out_y, h, corner_r);
      bosses(h);
    }
    translate([0, 0, wall]) rrect(cav_x, cav_y, cav_z + 1, 3);
    translate([0, 0, h - groove_d]) groove_cut();
    for (i = [-1, 1], j = [-1, 1])
      translate([i*boss_x, j*boss_y, h - insert_h])
        cylinder(h = insert_h + 1, d = insert_d);
  }
  translate([0, 0, wall - 0.01]) board_tray();
  battery_stops();
}

// ---------------------------------------------------------------------
module lid() {
  difference() {
    union() {
      rrect(out_x, out_y, lid_t, corner_r);
      bosses(lid_t);
      translate([0, 0, -lip_h])
        rrect(cav_x - 2*lip_gap, cav_y - 2*lip_gap, lip_h + 0.01, 3);
    }
    // LED window: a blind pocket from inside, window_t of wall left
    translate([window_off, 0, -lip_h - 0.01])
      cylinder(h = lip_h + lid_t - window_t + 0.01, d = window_d);
    // NFC tag pocket, on whichever face nfc_inside selects
    if (nfc_inside) {
      translate([nfc_off, 0, -lip_h - 0.01])
        cylinder(h = nfc_t + 0.01, d = nfc_d);
      // Engraved ring so the tap point stays findable
      translate([nfc_off, 0, lid_t - mark_t])
        difference() {
          cylinder(h = mark_t + 1, d = mark_d);
          translate([0, 0, -0.5]) cylinder(h = mark_t + 2, d = mark_d - 2*mark_w);
        }
    } else {
      translate([nfc_off, 0, lid_t - nfc_t])
        cylinder(h = nfc_t + 1, d = nfc_d);
    }
    // screws
    for (i = [-1, 1], j = [-1, 1]) translate([i*boss_x, j*boss_y, -1]) {
      cylinder(h = lid_t + 2, d = screw_d);
      translate([0, 0, lid_t - head_h + 1]) cylinder(h = head_h + 1, d = head_d);
    }
  }
}

// ---------------------------------------------------------------------
if (part == "body") body();
else if (part == "lid") translate([0, 0, lid_t]) rotate([180, 0, 0]) lid();
else {
  body();
  translate([0, 0, wall + cav_z + 12]) lid();
}

echo(str("Envelope: ", env_x, " x ", env_y, " x ", wall + cav_z + lid_t, " mm"));
echo(str("Cavity:   ", cav_x, " x ", cav_y, " x ", cav_z, " mm"));

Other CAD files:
enclosure/stl/lid-nfc-inside.stl

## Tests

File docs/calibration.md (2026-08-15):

# TX power calibration

**English** · [Français](calibration.fr.md)

The `TX_POWER_1M` byte is the single value that turns a raw RSSI into metres.
It is **the RSSI an iPhone reads at exactly 1 metre from the beacon**. Not a
setting to copy, not a datasheet figure — a measurement.

Get it wrong and every distance the app reports is wrong, in a way that looks
like a bug in your ranging code.

## Procedure

Do this once per beacon, in its final enclosure.

1. **Beacon in its closed enclosure**, with its battery in place. Plastic and a
   LiPo pouch easily cost 4–8 dB.
2. **About 1 m above ground**, on a non-metallic support, in the clear.
3. **iPhone at exactly 1 m**, held vertically, screen facing the beacon,
   nothing in between and **your body out of the line**. A human body absorbs
   10–15 dB at 2.4 GHz.
4. **Record the raw RSSI for 30 seconds** and take the **median**, not the
   mean. A single reflection skews an average.
5. Write that median into `TX_POWER_1M`. Reflash.
6. **Verify**: the app should now report roughly 1.0 m at 1 m.

## Use raw RSSI, not accuracy

`CLBeacon.accuracy` is *derived from* the TX power you are trying to set.
Calibrating against it is circular. You need `beacon.rssi`, in dBm.

Two implementation details: `rssi` returns 0 when iOS cannot measure — discard
those samples. And ranging runs at about 1 Hz with wide scatter, so display a
rolling median over 10 readings, or you will be reading values that jump by
±10 dB with no idea which one to write down.

## Calibrate each unit separately

Two boards of the same model will differ by several dB. If you calibrate one
and copy the value to the other, the second will consistently appear further
away at equal distance — and a child searching for it will notice.

A gap larger than about 5 dB between two units suggests a hardware problem
rather than normal variation.

## What good looks like

After calibration, expect roughly:

| Real distance | Reported |
|---|---|
| 1 m | ~1 m |
| 3 m | 2–4 m |
| 10 m | anywhere from 5 to 20 m |

**This is normal.** The conversion is logarithmic: at close range a few dB are
a few centimetres, at 10 m the same few dB are several metres. An iBeacon is
not a distance measuring instrument. Beyond about 5 m the estimate is
indicative at best.

Calibrate for the 0–3 m band — the one where the search actually happens — and
accept that the rest is approximate. Longer distances are the GPS stage's job.

## Path loss in the field

The distance model assumes a path loss exponent. Free space is 2.0; dense
vegetation runs 2.5 to 3.5. If your app exposes this, measure it outdoors in
the terrain you will actually use: it tells you how noisy your proximity
feedback will be before you find out with children in tow.

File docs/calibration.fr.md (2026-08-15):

# Calibration du TX power

[English](calibration.md) · **Français**

L'octet `TX_POWER_1M` est la seule valeur qui transforme un RSSI brut en
mètres. C'est **le RSSI que lit un iPhone à exactement 1 mètre de la balise**.
Pas un réglage à recopier, pas un chiffre de fiche technique : une mesure.

Une valeur fausse rend fausses toutes les distances affichées par
l'application, d'une manière qui ressemble à un bug dans votre code de ranging.

## Procédure

À faire une fois par balise, dans son boîtier définitif.

1. **Balise dans son boîtier fermé**, batterie en place. Le plastique et une
   poche LiPo coûtent facilement 4 à 8 dB.
2. **À environ 1 m du sol**, sur un support non métallique, dégagée.
3. **iPhone à exactement 1 m**, tenu vertical, écran face à la balise, rien
   entre les deux et **votre corps hors de l'axe**. Un corps humain absorbe
   10 à 15 dB à 2,4 GHz.
4. **Relevez le RSSI brut pendant 30 secondes** et prenez la **médiane**, pas la
   moyenne. Une seule réflexion décale une moyenne.
5. Écrivez cette médiane dans `TX_POWER_1M`. Reflashez.
6. **Vérifiez** : l'application doit maintenant afficher environ 1,0 m à 1 m.

## Utilisez le RSSI brut, pas accuracy

`CLBeacon.accuracy` est *calculé à partir* du TX power que vous cherchez à
régler. Calibrer dessus est circulaire. Il vous faut `beacon.rssi`, en dBm.

Deux détails d'implémentation : `rssi` renvoie 0 quand iOS ne sait pas mesurer,
filtrez ces échantillons. Et le ranging tourne à environ 1 Hz avec une forte
dispersion, donc affichez une médiane glissante sur 10 relevés, sinon vous
lirez des valeurs qui sautent de ±10 dB sans savoir laquelle noter.

## Calibrez chaque exemplaire séparément

Deux cartes du même modèle divergeront de plusieurs dB. Si vous calibrez l'une
et recopiez la valeur sur l'autre, la seconde paraîtra systématiquement plus
loin à distance égale — et un enfant qui la cherche s'en apercevra.

Un écart supérieur à 5 dB environ entre deux exemplaires évoque un problème
matériel plutôt qu'une variation normale.

## Ce qu'on doit obtenir

Après calibration, attendez-vous à peu près à :

| Distance réelle | Affichée |
|---|---|
| 1 m | ~1 m |
| 3 m | 2 à 4 m |
| 10 m | entre 5 et 20 m |

**C'est normal.** La conversion est logarithmique : à courte distance quelques
dB font quelques centimètres, à 10 m les mêmes quelques dB font plusieurs
mètres. Un iBeacon n'est pas un instrument de mesure de distance. Au-delà de
5 m environ, l'estimation est au mieux indicative.

Calibrez pour la plage 0 à 3 m — celle où la recherche a réellement lieu — et
acceptez que le reste soit approximatif. Les longues distances sont le travail
de l'étage GPS.

## Affaiblissement sur le terrain

Le modèle de distance suppose un exposant d'affaiblissement. L'espace libre
vaut 2,0 ; une végétation dense se situe entre 2,5 et 3,5. Si votre application
expose ce paramètre, mesurez-le en extérieur dans le terrain que vous
utiliserez : il vous dira à quel point votre retour de proximité sera bruité,
avant de le découvrir avec des enfants sur les bras.

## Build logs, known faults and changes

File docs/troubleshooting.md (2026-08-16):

# Troubleshooting

**English** · [Français](troubleshooting.fr.md)

## nRF Connect on iPhone shows nothing

**This is expected. It is not a fault in your beacon.**

iOS filters Apple manufacturer data (`0x004C`) out of CoreBluetooth. Any iOS
app scanning that way sees an empty packet — no UUID, no major, no minor, no
iBeacon badge. The same beacon shown in nRF Connect for Android displays
everything.

On iPhone, **CoreLocation is the only way to see an iBeacon**. Do not use an
iOS scanner app to debug a beacon.

To inspect raw frames, use one of:

- **A Mac.** Macs do not apply the same filter. LightBlue works.
- **`firmware/scanner`** on a second ESP32.
- **An Android phone** with nRF Connect.

## Nothing detected, in order of likelihood

**1. UUID mismatch.** By far the most common cause, and it fails silently —
CoreLocation reports nothing rather than an error. Compare the UUID in the app
against bytes 4–19 of the advertised payload, in that exact order.

**2. Missing Info.plist key.** `NSLocationWhenInUseUsageDescription` must be
present. Without it iOS refuses silently: no crash, no error, nothing.

**3. Authorisation not granted.** `requestWhenInUseAuthorization()` must be
called and the dialog accepted. Check in Settings → your app → Location.

**4. Monitoring instead of ranging.** They are different APIs.
`startRangingBeacons(satisfying:)` is the one that yields RSSI and distance.

**5. CLLocationManager not retained.** A manager declared as a local variable
is deallocated when the function returns, and ranging stops with no message.
Hold it in a property.

**6. Filtering on a full minor.** Constrain on UUID and major only. The low
byte of minor carries battery level and changes as the cell drains — a filter
on the complete minor will stop matching.

## Verifying the beacon side

Open the serial monitor at 115200. The firmware prints the payload before
advertising starts:

```
AD mfg (25 bytes): 1A FF 4C 00 02 15 A4 C2 ...
Advertising total: 30 / 31 bytes
Advertising: YES
```

If `4C 00 02 15` follows `1A FF`, the frame is correct. If `Advertising` says
`NO`, the stack refused to start and the problem is on the board.

If the dump is correct **and** advertising is on, the beacon is almost
certainly fine and the problem is in the app.

## Compilation errors

### `'ADV_TYPE_NONCONN_IND' was not declared in this scope`

That constant belongs to Bluedroid. On NimBLE targets such as the ESP32-C6 it
does not exist. Delete the `setAdvertisementType()` line — the shipped firmware
already omits it.

The beacon then advertises as connectable rather than non-connectable. Apple's
specification calls for non-connectable, but CoreLocation ranges both
identically and commercial beacons ship connectable.

### Board not in the list

C6 and H2 targets require ESP32 core **3.x**. Update the core, not your search.

### No serial port

Native-USB boards only enumerate once running, and the port disappears at each
reset. Double-press RESET to force the bootloader. Check the cable is a data
cable — charge-only USB cables are the classic time sink.

### Everything compiles but the serial monitor goes quiet

Arduino-ESP32 builds RISC-V targets against **newlib-nano**, which does not
implement floating point formatting. A single `%f` in a `Serial.printf` can
swallow the whole line or print garbage — and the failure looks like the board
has stopped rather than a formatting bug.

The shipped firmware uses integer maths everywhere for this reason:
`DIVIDER_X100` and `BAT_CAL_X1000` are scaled integers printed with
division and modulo. Keep it that way.

### `redefinition of 'setup()'` and a dozen similar errors

The Arduino IDE concatenates **every `.ino` in a sketch folder** before
compiling. Two firmware variants side by side means two `setup()`, two
`BEACON_UUID`, and so on.

One sketch per folder, and the folder name must match the `.ino` name. Avoid
spaces in sketch names while you are at it.

## Distances are wrong

Consistently **too short** means `TX_POWER_1M` is too low. Consistently too
long means it is too high. Do not tune by trial and error — measure at 1 m, see
[calibration](calibration.md).

Errors growing with distance are inherent to the logarithmic model, not a
calibration fault. Beyond 5 m an iBeacon estimate is indicative at best.

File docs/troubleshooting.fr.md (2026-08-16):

# Dépannage

[English](troubleshooting.md) · **Français**

## nRF Connect sur iPhone n'affiche rien

**C'est le comportement attendu. Ce n'est pas un défaut de votre balise.**

iOS filtre les données constructeur Apple (`0x004C`) dans CoreBluetooth. Toute
application iOS scannant de cette manière ne voit qu'un paquet vide : ni UUID,
ni major, ni minor, ni badge iBeacon. La même balise affiche tout dans nRF
Connect pour Android.

Sur iPhone, **CoreLocation est le seul moyen de voir un iBeacon**. N'utilisez
pas une application de scan iOS pour déboguer une balise.

Pour inspecter les trames brutes, utilisez l'une de ces options :

- **Un Mac.** Les Mac n'appliquent pas le même filtre. LightBlue fait l'affaire.
- **`firmware/scanner`** sur un second ESP32.
- **Un téléphone Android** avec nRF Connect.

## Rien n'est détecté, par ordre de probabilité

**1. UUID différent.** De loin la cause la plus fréquente, et l'échec est
silencieux : CoreLocation ne remonte rien plutôt qu'une erreur. Comparez l'UUID
de l'application aux octets 4 à 19 de la trame émise, dans cet ordre exact.

**2. Clé Info.plist manquante.** `NSLocationWhenInUseUsageDescription` doit être
présente. Sans elle, iOS refuse en silence : pas de crash, pas d'erreur, rien.

**3. Autorisation non accordée.** `requestWhenInUseAuthorization()` doit être
appelée et la boîte de dialogue acceptée. Vérifiez dans Réglages → votre
application → Position.

**4. Monitoring au lieu de ranging.** Ce sont deux API distinctes.
`startRangingBeacons(satisfying:)` est celle qui donne RSSI et distance.

**5. CLLocationManager non retenu.** Un manager déclaré en variable locale est
désalloué à la sortie de la fonction, et le ranging s'arrête sans le moindre
message. Conservez-le dans une propriété.

**6. Filtrage sur un minor complet.** Contraignez sur UUID et major seulement.
L'octet bas du minor porte le niveau de batterie et change au fil de la
décharge : un filtre sur le minor entier cessera de correspondre.

## Vérifier le côté balise

Ouvrez le moniteur série à 115200. Le firmware imprime la trame avant de
démarrer l'advertising :

```
AD mfg (25 bytes): 1A FF 4C 00 02 15 A4 C2 ...
Advertising total: 30 / 31 bytes
Advertising: YES
```

Si `4C 00 02 15` suit `1A FF`, la trame est correcte. Si `Advertising` indique
`NO`, la pile a refusé de démarrer et le problème est sur la carte.

Si le dump est correct **et** l'advertising actif, la balise est presque
certainement bonne et le problème se situe dans l'application.

## Erreurs de compilation

### `'ADV_TYPE_NONCONN_IND' was not declared in this scope`

Cette constante appartient à Bluedroid. Sur les cibles NimBLE comme l'ESP32-C6,
elle n'existe pas. Supprimez la ligne `setAdvertisementType()` — le firmware
fourni l'omet déjà.

La balise émet alors en connectable plutôt qu'en non-connectable. La
spécification d'Apple prévoit le non-connectable, mais CoreLocation range les
deux de façon identique et des balises du commerce émettent en connectable.

### Carte absente de la liste

Les cibles C6 et H2 nécessitent le core ESP32 **3.x**. Mettez le core à jour,
plutôt que de chercher dans la liste.

### Pas de port série

Les cartes en USB natif ne s'énumèrent qu'une fois démarrées, et le port
disparaît à chaque reset. Double appui sur RESET pour forcer le bootloader.
Vérifiez que le câble est bien un câble de données — les câbles USB de charge
seule sont le piège classique.

### Tout compile mais le moniteur série devient muet

Arduino-ESP32 compile les cibles RISC-V avec **newlib-nano**, qui n'implémente
pas le formatage des flottants. Un seul `%f` dans un `Serial.printf` peut
avaler la ligne entière ou afficher n'importe quoi — et le symptôme ressemble à
une carte plantée, pas à un problème de formatage.

C'est pourquoi le firmware fourni travaille exclusivement en entiers :
`DIVIDER_X100` et `BAT_CAL_X1000` sont des entiers mis à l'échelle, affichés
par division et modulo. Conservez ce principe.

### `redefinition of 'setup()'` et une dizaine d'erreurs semblables

L'IDE Arduino concatène **tous les `.ino` d'un dossier de croquis** avant de
compiler. Deux variantes de firmware côte à côte, c'est deux `setup()`, deux
`BEACON_UUID`, et ainsi de suite.

Un croquis par dossier, et le nom du dossier doit correspondre à celui du
`.ino`. Profitez-en pour éviter les espaces dans les noms.

## Les distances sont fausses

Systématiquement **trop courtes** : `TX_POWER_1M` est trop bas. Systématiquement
trop longues : il est trop haut. N'ajustez pas à tâtons, mesurez à 1 m, voir
[calibration](calibration.fr.md).

Des erreurs qui grandissent avec la distance sont inhérentes au modèle
logarithmique, pas un défaut de calibration. Au-delà de 5 m, une estimation
iBeacon est au mieux indicative.

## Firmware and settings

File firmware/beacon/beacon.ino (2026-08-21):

// =====================================================================
//  Treasure Hunt - Beacon firmware
//  https://github.com/MadeInFck/TreasureHuntBeacon
//
//  Single source for every supported board. Set TARGET_BOARD below,
//  then HUNT_ID and STEP_ID, then calibrate TX_POWER_1M.
//
//  ONE SKETCH PER FOLDER: the Arduino IDE concatenates every .ino in a
//  sketch folder before compiling. Keep only this file in firmware/beacon/,
//  or you get "redefinition of setup()" and friends.
//
//  ---------------------------------------------------------------------
//  Hard-won notes from bringing this up. Do not undo these.
//
//  * The manufacturer payload is built byte by byte, not via BLEBeacon.
//    That class applies ENDIAN_CHANGE_U16 internally and which fields it
//    touches has varied across core versions. Hand-built bytes are also
//    immune to the Bluedroid/NimBLE split.
//
//  * No setAdvertisementType(ADV_TYPE_NONCONN_IND). That constant is
//    Bluedroid-only and does not compile on NimBLE targets such as the
//    ESP32-C6. Apple's spec wants non-connectable, but CoreLocation
//    ranges connectable beacons identically.
//
//  * BLEDevice::init("") with an EMPTY name. Flags plus the manufacturer
//    structure already use 30 of the 31 available bytes; any name
//    overflows and the beacon silently disappears.
//
//  * NO %f ANYWHERE in Serial.printf. Arduino-ESP32 builds RISC-V targets
//    against newlib-nano, which does not implement floating point
//    formatting. A single %f can swallow the whole line or print garbage.
//    All ratios below are printed with integer maths.
//
//  * nRF Connect on iPhone will NEVER show this beacon. iOS filters
//    Apple manufacturer data out of CoreBluetooth. Verify with a Mac,
//    an Android phone, firmware/scanner, or your own CoreLocation app.
//
//  * TX_POWER_1M is a MEASUREMENT, not a setting. See docs/calibration.md.
//
//  * LOLIN C3 Pico VBAT: the divider IS on the board, but WEMOS ships it
//    DISCONNECTED so GPIO3 stays free. Bridge the two solder pads on the
//    underside to enable it. Measured after bridging: 2010 mV at the pin
//    for a 4.01 V cell -- a 1.995:1 ratio, so DIVIDER_X100 = 200 is right.
//
//  * The cutoff reads the DIVIDER, never the USB rail. With no cell
//    plugged in, the divider is fed by nothing and the pin floats around
//    400 mV, which looks exactly like a flat cell and used to put the
//    board straight into deep sleep -- taking the native USB port with
//    it. BAT_ABSENT_MV is the floor that tells the two cases apart.
// =====================================================================

#include <BLEDevice.h>
#include <BLEUtils.h>
#include <esp_sleep.h>

// ---- BOARD SELECTION ------------------------------------------------
#define BOARD_LOLIN_C3_PICO  1
#define BOARD_M5_NANO_C6     2
#define BOARD_GENERIC        3

#define TARGET_BOARD  BOARD_LOLIN_C3_PICO     // <<< SET THIS

// ---- PER-BEACON SETTINGS --------------------------------------------
#define HUNT_ID      1        // hunt number, MAJOR. Same across one hunt.
#define STEP_ID      1        // step number, high byte of MINOR. One per beacon.
#define TX_POWER_1M  (-62)    // raw RSSI an iPhone reads at 1 m. MEASURE IT,
                              // per unit, in the final enclosure.

// ---- FEATURES -------------------------------------------------------
#define ENABLE_BATTERY_TELEMETRY  1   // 1 only once a VBAT divider is confirmed
#define ENABLE_ADC_PROBE          0   // 1 to hunt for a divider on BAT_ADC_PIN
#define ENABLE_LOW_VOLTAGE_CUTOFF 1   // stop and sleep before the cell is ruined

// The cutoff needs a voltage reading. Without telemetry there is nothing
// to act on, so it disables itself rather than pretend to protect.
#if ENABLE_LOW_VOLTAGE_CUTOFF && !ENABLE_BATTERY_TELEMETRY
  #undef  ENABLE_LOW_VOLTAGE_CUTOFF
  #define ENABLE_LOW_VOLTAGE_CUTOFF 0
  #define CUTOFF_UNAVAILABLE        1
#endif

// ---- BATTERY --------------------------------------------------------
#define BAT_NOMINAL_MV  4000  // your measured cell voltage, used by the probe
#define DIVIDER_X100    200   // divider ratio x100. Verified 1.995:1 -> 200
                              // on a bridged LOLIN C3 Pico.
#define BAT_CAL_X1000   1000  // trim x1000. Measured within 0.5%: no correction.
#define BAT_SAMPLES     9     // odd, median filtered
#define BAT_PERIOD_MS   60000 // frame refresh cadence; 10000 while testing
#define BAT_HYSTERESIS  2     // 2 steps = 20 mV before the frame is rewritten

#define BAT_LOW_MV      3500  // heartbeat turns yellow below this
#define BAT_CRIT_MV     3300  // heartbeat turns red below this
#define BAT_CUTOFF_MV   3200  // below this the beacon shuts itself down
#define BAT_ABSENT_MV   2500  // BELOW this, assume NO CELL rather than a dead
                              // one, and do not cut off. A LiPo genuinely at
                              // 2.5 V is scrap anyway, so this floor hides no
                              // real case -- but it keeps a USB-only board out
                              // of deep sleep, which is how you develop.
#define CUTOFF_STRIKES  3     // consecutive readings before acting, so a single
                              // sag during a radio burst cannot trigger it
#define CUTOFF_GRACE_MS 10000 // warning window at boot before sleeping, so the
                              // board stays reachable

// ---- ADC PROBE ------------------------------------------------------
#define PROBE_PERIOD_MS 3000  // fast enough to watch a cell being plugged in
#define PROBE_FLOOR_MV  150   // below this the pin reads as floating
#define PROBE_SPREAD_PC 2     // spread over this % of the reading = floating

// ---- STATUS LED -----------------------------------------------------
#define LED_NONE        0
#define LED_SIMPLE      1     // plain on/off LED via digitalWrite
#define LED_RGB         2     // WS2812 via neopixelWrite

// One colour per meaning, no colour used twice. RED IS RESERVED FOR
// ALARM: never reuse it for a count.
// Violet on a WS2812 is red+blue mixed; 180/0/255 keeps it clearly
// distinct from the pure blue of the step count through a diffuser.
// The low-battery colour needs its green channel high: below about 150
// the red dominates and it reads as orange, or as red at low brightness.
#define COL_BOOT     255, 255, 255   // white  - power-up flash
#define COL_HUNT     180,   0, 255   // violet - hunt number count
#define COL_STEP       0,   0, 255   // blue   - step number count
#define COL_ALIVE      0, 255,   0   // green  - heartbeat, all well
#define COL_LOW      255, 200,   0   // yellow - heartbeat, battery low
#define COL_CRIT     255,   0,   0   // red    - heartbeat, battery critical

#define LED_BRIGHTNESS  24    // identify phase. Full tilt draws ~60 mA/channel.
#define BEAT_BRIGHTNESS 6     // heartbeat: dim, but the colour stays readable
#define BLINK_ON_MS     250   // one count blink
#define BLINK_OFF_MS    350   // gap between blinks of the same group
#define GROUP_GAP_MS    1000  // gap BETWEEN groups: makes 1 violet + 1 blue legible
#define SETTLE_MS       2000  // before the heartbeat starts, or the first
                              // pulse gets counted as an extra blink
#define HEARTBEAT_MS    5000
#define BEAT_ON_MS      40

// ---- BOARD MAP ------------------------------------------------------
#if   TARGET_BOARD == BOARD_LOLIN_C3_PICO
  #define LED_TYPE       LED_RGB
  #define LED_PIN        7     // WS2812, confirmed on this board
  #define LED_POWER_PIN  (-1)  // none
  #define BAT_ADC_PIN    3     // GPIO3 = A3 = ADC1_CH3. NEVER GPIO2 (strapping).
                               // Requires the underside solder bridge, see header.
#elif TARGET_BOARD == BOARD_M5_NANO_C6
  #define LED_TYPE       LED_RGB
  #define LED_PIN        20    // VERIFY against your board pinout
  #define LED_POWER_PIN  19    // VERIFY: RGB power enable, driven HIGH
  #define BAT_ADC_PIN    1     // Grove white wire, ADC1. No on-board divider.
#else
  #define LED_TYPE       LED_NONE
  #define LED_PIN        (-1)
  #define LED_POWER_PIN  (-1)
  #define BAT_ADC_PIN    1     // pick any free ADC1 pin
#endif

// Project UUID A4C27B10-5F3E-4E2A-9D8C-1B6F0E3D7A52, big-endian on air.
// Fixed for the whole project: the app filters on this exact value.
static const uint8_t BEACON_UUID[16] = {
  0xA4, 0xC2, 0x7B, 0x10, 0x5F, 0x3E, 0x4E, 0x2A,
  0x9D, 0x8C, 0x1B, 0x6F, 0x0E, 0x3D, 0x7A, 0x52
};

static uint8_t         mfg[25];   // library prepends length (0x1A) and type (0xFF)
static BLEAdvertising *pAdv      = NULL;
static uint8_t         lastBat   = 0x00;
static uint8_t         beatR = 0, beatG = 255, beatB = 0;   // heartbeat colour
static uint32_t        lastCheck = 0, beatStart = 0;
static bool            ledOn     = false;
static uint8_t         strikes   = 0;

#if ENABLE_ADC_PROBE
static uint16_t probeMin = 0xFFFF, probeMax = 0;   // spread since boot
#endif

// ---------------------------------------------------------------------
//  Status LED
// ---------------------------------------------------------------------
static void ledInit() {
#if LED_TYPE == LED_RGB
  if (LED_POWER_PIN >= 0) { pinMode(LED_POWER_PIN, OUTPUT); digitalWrite(LED_POWER_PIN, HIGH); }
#elif LED_TYPE == LED_SIMPLE
  pinMode(LED_PIN, OUTPUT);
  digitalWrite(LED_PIN, LOW);
#endif
}

// Full-strength colour, used by the boot flash and the two counts.
static void ledSet(uint8_t r, uint8_t g, uint8_t b) {
#if LED_TYPE == LED_RGB
  neopixelWrite(LED_PIN, (r * LED_BRIGHTNESS) / 255,
                         (g * LED_BRIGHTNESS) / 255,
                         (b * LED_BRIGHTNESS) / 255);
#elif LED_TYPE == LED_SIMPLE
  digitalWrite(LED_PIN, (r || g || b) ? HIGH : LOW);
#else
  (void)r; (void)g; (void)b;
#endif
}

static void ledOff() { ledSet(0, 0, 0); }

// Dimmed heartbeat, four times fainter than the counts and six times
// shorter, so the two can never be mistaken for one another.
static void ledBeat() {
#if LED_TYPE == LED_RGB
  neopixelWrite(LED_PIN, (beatR * BEAT_BRIGHTNESS) / 255,
                         (beatG * BEAT_BRIGHTNESS) / 255,
                         (beatB * BEAT_BRIGHTNESS) / 255);
#elif LED_TYPE == LED_SIMPLE
  digitalWrite(LED_PIN, HIGH);
#endif
}

// Heartbeat colour follows the cell. mv == 0 means "no telemetry", which
// is not a fault, so it stays green.
static void setBeatColor(uint16_t mv) {
  uint8_t c[3];
  if      (mv == 0)          { uint8_t t[] = {COL_ALIVE}; memcpy(c, t, 3); }
  else if (mv < BAT_CRIT_MV) { uint8_t t[] = {COL_CRIT};  memcpy(c, t, 3); }
  else if (mv < BAT_LOW_MV)  { uint8_t t[] = {COL_LOW};   memcpy(c, t, 3); }
  else                       { uint8_t t[] = {COL_ALIVE}; memcpy(c, t, 3); }
  beatR = c[0]; beatG = c[1]; beatB = c[2];
}

static void blinkCount(uint8_t n, uint8_t r, uint8_t g, uint8_t b) {
  for (uint8_t i = 0; i < n; i++) {
    ledSet(r, g, b);
    delay(BLINK_ON_MS);
    ledOff();
    delay(BLINK_OFF_MS);
  }
}

// White flash, then HUNT_ID in violet, then STEP_ID in blue. Reads the
// whole identity of the beacon without a phone. GROUP_GAP_MS between the
// two counts is what makes "one violet, one blue" legible.
static void identify() {
  ledSet(COL_BOOT);
  delay(400);
  ledOff();
  delay(600);

  blinkCount(HUNT_ID, COL_HUNT);
  delay(GROUP_GAP_MS - BLINK_OFF_MS);

  blinkCount(STEP_ID, COL_STEP);
  delay(SETTLE_MS);
}

// ---------------------------------------------------------------------
//  ADC -- all integer maths, no floating point anywhere
// ---------------------------------------------------------------------
static uint16_t readPinMv(uint8_t pin) {
  uint32_t s[BAT_SAMPLES];
  for (int i = 0; i < BAT_SAMPLES; i++) {
    s[i] = analogReadMilliVolts(pin);           // applies eFuse calibration
    delay(2);                                   // radio bursts sag the rail
  }
  for (int i = 1; i < BAT_SAMPLES; i++) {       // insertion sort, n = 9
    uint32_t v = s[i]; int j = i - 1;
    while (j >= 0 && s[j] > v) { s[j + 1] = s[j]; j--; }
    s[j + 1] = v;
  }
  return (uint16_t)s[BAT_SAMPLES / 2];          // median, not mean
}

static uint16_t pinToBattery(uint16_t pinMv) {
  return (uint16_t)(((uint32_t)pinMv * DIVIDER_X100 * BAT_CAL_X1000) / 100000UL);
}

static uint16_t readBatteryMv() {
  return pinToBattery(readPinMv(BAT_ADC_PIN));
}

static uint16_t expectedPinMv() {
  return (uint16_t)(((uint32_t)BAT_NOMINAL_MV * 100) / DIVIDER_X100);
}

#if ENABLE_ADC_PROBE
// Spread since boot, judged as a PERCENTAGE of the reading. A fixed
// millivolt threshold called 26 mV on a 430 mV reading "steady" when it
// was really 6% of noise. Proportional is the honest test.
static void probeAdc() {
  uint16_t mv = readPinMv(BAT_ADC_PIN);

  if (mv < probeMin) probeMin = mv;
  if (mv > probeMax) probeMax = mv;
  uint16_t spread   = probeMax - probeMin;
  uint16_t expected = expectedPinMv();

  const char *verdict;
  if (mv < PROBE_FLOOR_MV)                                verdict = "floating (near zero)";
  else if (spread * 100 > (uint32_t)mv * PROBE_SPREAD_PC) verdict = "noisy -> floating";
  else if (abs((int)mv - (int)expected) < 200)            verdict = "MATCH -> divider!";
  else                                                    verdict = "steady but wrong level";

  Serial.printf("GPIO%d : %4u mV | spread %3u mV (%2u%%) | expect %4u mV | %s\n",
                BAT_ADC_PIN, mv, spread,
                mv ? (uint16_t)(((uint32_t)spread * 100) / mv) : 0, expected, verdict);
}
#endif

// Spec: voltage_mV = 2500 + byte * 10, byte 0x00 means "no telemetry".
// Clamp to 1 so a flat cell never emits the sentinel by accident.
static uint8_t encodeBattery(uint16_t mv) {
  if (mv < 2510) return 1;
  uint16_t v = (mv - 2500) / 10;
  return v > 255 ? 255 : (uint8_t)v;
}

// ---------------------------------------------------------------------
//  Low-voltage cutoff
//
//  A beacon left switched on after a hunt would otherwise discharge its
//  cell until the ESP32 browns out, well past the point where a LiPo
//  takes permanent damage. This stops advertising and enters deep sleep
//  with NO wake source: the beacon stays off until it is power-cycled,
//  by which time you will be charging it anyway.
//
//  Deep sleep does not reach microamps on these boards -- the WS2812 and
//  the regulator keep drawing on the order of a milliamp. It still cuts
//  the drain by roughly fifty times, which is the point. The switch in
//  series with the cell remains the only true zero.
//
//  It fires ONLY between BAT_ABSENT_MV and BAT_CUTOFF_MV. Below the
//  floor there is no cell on the divider, and sleeping would just make
//  the board unreachable for no benefit.
// ---------------------------------------------------------------------
#if ENABLE_LOW_VOLTAGE_CUTOFF
static bool cellIsFlat(uint16_t mv) {
  return mv >= BAT_ABSENT_MV && mv < BAT_CUTOFF_MV;
}

static void shutdownFlat(uint16_t mv, bool grace) {
  Serial.printf("\nCUTOFF: %u mV is below %u mV.\n", mv, BAT_CUTOFF_MV);
  if (grace)
    Serial.printf("Sleeping in %u s -- double-tap RESET now to keep the port.\n",
                  CUTOFF_GRACE_MS / 1000);
  Serial.println("Charge the cell and power-cycle to restart.");
  Serial.flush();

  if (pAdv) pAdv->stop();

  // Deep sleep takes the native USB port down with it, so warn visibly
  // and leave a window before it happens.
  uint32_t blinks = grace ? (CUTOFF_GRACE_MS / 800) : 3;
  for (uint32_t i = 0; i < blinks; i++) {
    ledSet(COL_CRIT);
    delay(400);
    ledOff();
    delay(400);
  }
  esp_deep_sleep_start();                     // no wake source configured
}
#endif

// ---------------------------------------------------------------------
//  iBeacon payload
// ---------------------------------------------------------------------
static void buildPayload(uint8_t bat) {
  uint16_t minor = ((uint16_t)STEP_ID << 8) | bat;

  mfg[0]  = 0x4C;  mfg[1]  = 0x00;            // Apple company ID, little-endian
  mfg[2]  = 0x02;  mfg[3]  = 0x15;            // iBeacon subtype + remaining length
  memcpy(&mfg[4], BEACON_UUID, 16);           // UUID, big-endian
  mfg[20] = (HUNT_ID >> 8) & 0xFF;            // MAJOR, big-endian
  mfg[21] =  HUNT_ID       & 0xFF;
  mfg[22] = (minor   >> 8) & 0xFF;            // MINOR, big-endian
  mfg[23] =  minor         & 0xFF;
  mfg[24] = (uint8_t)(int8_t)TX_POWER_1M;     // -59 -> 0xC5
}

static void publish(uint8_t bat) {
  buildPayload(bat);

  BLEAdvertisementData adv;
  adv.setFlags(0x04);                         // BR/EDR not supported
#if ESP_ARDUINO_VERSION_MAJOR >= 3
  adv.setManufacturerData(String((char *)mfg, sizeof(mfg)));
#else
  adv.setManufacturerData(std::string((char *)mfg, sizeof(mfg)));
#endif

  pAdv->stop();                               // required before rewriting
  pAdv->setAdvertisementData(adv);
  pAdv->start();
}

static void dumpPayload() {
  Serial.printf("AD mfg (%u bytes): 1A FF", sizeof(mfg));
  for (size_t i = 0; i < sizeof(mfg); i++) Serial.printf(" %02X", mfg[i]);
  Serial.printf("\nAdvertising total: %u / 31 bytes\n", 3 + 2 + sizeof(mfg));
  Serial.println("Expect 1A FF 4C 00 02 15 ... -- anything else and iOS ignores it.");
}

// ---------------------------------------------------------------------
void setup() {
  Serial.begin(115200);
  delay(300);
  Serial.println("\n=== Treasure Hunt beacon ===");

  ledInit();
  ledOff();

#if ENABLE_BATTERY_TELEMETRY || ENABLE_ADC_PROBE
  analogSetPinAttenuation(BAT_ADC_PIN, ADC_11db);      // ~0 to 3.1 V range
#endif
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
void loop() {
  uint32_t now = millis();

#if ENABLE_ADC_PROBE
  if (now - lastCheck >= PROBE_PERIOD_MS) {
    lastCheck = now;
    probeAdc();
  }
#elif ENABLE_BATTERY_TELEMETRY
  if (now - lastCheck >= BAT_PERIOD_MS) {
    lastCheck = now;

    uint16_t pinMv = readPinMv(BAT_ADC_PIN);
    uint16_t batMv = pinToBattery(pinMv);
    uint8_t  bat   = encodeBattery(batMv);

    Serial.printf("[%6us] pin %4u mV | VBAT %4u mV | code %3u | minor 0x%04X",
                  (unsigned)(now / 1000), pinMv, batMv, bat,
                  (STEP_ID << 8) | bat);

    // Hysteresis keeps MINOR from flickering on ADC noise, which would
    // make the app's device list churn.
    if (abs((int)bat - (int)lastBat) >= BAT_HYSTERESIS) {
      lastBat = bat;
      setBeatColor(batMv);
      publish(bat);
      Serial.print("  <- frame updated");
    }

  #if ENABLE_LOW_VOLTAGE_CUTOFF
    if (cellIsFlat(batMv)) {
      strikes++;
      Serial.printf("  <- below cutoff (%u/%u)", strikes, CUTOFF_STRIKES);
      if (strikes >= CUTOFF_STRIKES) { Serial.println(); shutdownFlat(batMv, false); }
    } else {
      strikes = 0;
    }
  #endif

    Serial.println();
  }
#endif

  if (ledOn) {
    if (now - beatStart >= BEAT_ON_MS) { ledOff(); ledOn = false; }
  } else if (now - beatStart >= HEARTBEAT_MS) {
    ledBeat();
    ledOn = true;
    beatStart = now;
  }

  delay(10);   // advertising runs in the BLE stack, independent of loop()
}

// =====================================================================
//  LED CODE
//
//  At power-up, once:
//    1 white flash        beacon is booting
//    N violet blinks      hunt number   (HUNT_ID / MAJOR)
//      -- one second pause --
//    M blue blinks        step number   (STEP_ID)
//
//  Then, forever, one brief pulse every 5 s:
//    green                alive, battery fine or not measured
//    yellow               battery below BAT_LOW_MV
//    red                  battery below BAT_CRIT_MV
//
//  Slow red blinks with no identify sequence: the low-voltage cutoff
//  fired. Charge the cell and power-cycle. Recover the board with a
//  double-tap on RESET -- the ROM bootloader runs regardless of deep
//  sleep, and the port comes back.
//
//  Arm the beacon, count violet, count blue, check the pulse colour,
//  close the box. That is the whole pre-flight check, no phone needed.
//
//  RED IS RESERVED FOR ALARM and appears nowhere else.
//
//  ---------------------------------------------------------------------
//  BRINGING UP A NEW BEACON
//
//  1. Set TARGET_BOARD, HUNT_ID and STEP_ID. Flash. Label the board
//     physically right now -- two identical boards are indistinguishable
//     later.
//
//  2. Serial monitor at 115200. The dump must show 1A FF 4C 00 02 15,
//     and Advertising must say YES. If not, stop here.
//
//  3. Confirm the frame with a Mac (LightBlue), an Android phone, or
//     firmware/scanner. NOT nRF Connect on iPhone -- it cannot see
//     iBeacons at all.
//
//  4. Range it from your app. If nothing appears, the UUID is the first
//     suspect, then Info.plist, then a CLLocationManager that was not
//     retained, then a filter on the full minor.
//
//  5. Calibrate TX_POWER_1M: raw RSSI at exactly 1 m, median over 30 s,
//     body out of the line, beacon in its closed enclosure. Per unit.
//
//  6. Battery, LOLIN C3 Pico: bridge the two solder pads on the
//     underside to connect the cell to the on-board divider on GPIO3.
//     WEMOS ships it open so the pin stays free. Once bridged the
//     divider draws current continuously while a cell is connected,
//     which is why the switch belongs in series with the battery.
//
//     On boards with no divider at all, wire your own:
//
//        switched battery + ---- R1 100k ----+---- R2 100k ---- GND
//                                            |
//                                            +---- C1 100nF --- GND
//                                            |
//                                            +---- BAT_ADC_PIN
//
//  7. Before hiding a beacon outdoors, consider setting LED_TYPE to
//     LED_NONE. A blinking box under a rock is a clue you did not mean
//     to give.
// =====================================================================

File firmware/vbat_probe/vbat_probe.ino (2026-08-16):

// =====================================================================
//  Treasure Hunt - Differential VBAT probe (ESP32-C3)
//  https://github.com/MadeInFck/TreasureHuntBeacon
//
//  Standalone diagnostic sketch. Does NOT advertise. Its only job is to
//  answer one question: does this board wire the battery to an ADC pin?
//
//  Single readings prove nothing here -- every unconnected pin floats
//  somewhere in the 400-600 mV range, and both a fixed and a
//  proportional stability threshold gave misleading verdicts. What does
//  prove something is a DIFFERENCE: a pin fed by a VBAT divider moves by
//  hundreds of millivolts when the cell is plugged in. A floating pin
//  stays inside its own noise.
//
//  ---------------------------------------------------------------------
//  HOW TO USE
//
//   1. Flash with the cell DISCONNECTED. Keep USB plugged in.
//   2. Open the serial monitor at 115200. Set the line ending to
//      "Newline" or "Both NL & CR" so the sketch sees your Enter.
//   3. Phase A samples for ~30 s on its own.
//   4. When prompted, plug the cell into the PH-2.0 port and press
//      Enter in the serial monitor.
//   5. Phase B samples for another ~30 s, then prints the verdict.
//
//  Only GPIO0..GPIO4 are scanned. Those are the ESP32-C3's ADC1
//  channels. GPIO5 is on ADC2, which is unreliable while the radio is
//  active, and every other pin returns meaningless values.
// =====================================================================

#define PHASE_SECONDS   30    // sampling window per phase
#define SAMPLE_EVERY_MS 500   // one sweep per pin at this cadence
#define BAT_NOMINAL_MV  4000  // measured cell voltage, for the expected level

#define DELTA_SIGNIFICANT 250 // mV of movement that cannot be noise
#define NOISE_BAND_MV      80 // expected spread of a floating pin

// ESP32-C3 ADC1 channels. Do not extend this list.
static const uint8_t PINS[] = {0, 1, 2, 3, 4};
static const uint8_t NPINS  = sizeof(PINS);

struct Stats {
  uint32_t sum;
  uint16_t n, lo, hi;
};

static Stats phaseA[5], phaseB[5];

// ---------------------------------------------------------------------
static void resetStats(Stats *s) {
  for (uint8_t i = 0; i < NPINS; i++) { s[i].sum = 0; s[i].n = 0; s[i].lo = 0xFFFF; s[i].hi = 0; }
}

static uint16_t medianOf9(uint8_t pin) {
  uint32_t v[9];
  for (uint8_t i = 0; i < 9; i++) { v[i] = analogReadMilliVolts(pin); delay(2); }
  for (uint8_t i = 1; i < 9; i++) {           // insertion sort
    uint32_t t = v[i]; int j = i - 1;
    while (j >= 0 && v[j] > t) { v[j + 1] = v[j]; j--; }
    v[j + 1] = t;
  }
  return (uint16_t)v[4];
}

static void sampleInto(Stats *s) {
  for (uint8_t i = 0; i < NPINS; i++) {
    uint16_t mv = medianOf9(PINS[i]);
    s[i].sum += mv;
    s[i].n++;
    if (mv < s[i].lo) s[i].lo = mv;
    if (mv > s[i].hi) s[i].hi = mv;
  }
}

static uint16_t meanOf(const Stats &s) {
  return s.n ? (uint16_t)(s.sum / s.n) : 0;
}

static void runPhase(const char *label, Stats *dest) {
  resetStats(dest);
  Serial.printf("\n--- Phase %s: sampling %u s ---\n", label, PHASE_SECONDS);

  uint32_t end = millis() + (uint32_t)PHASE_SECONDS * 1000UL;
  uint8_t  dots = 0;
  while (millis() < end) {
    sampleInto(dest);
    if (++dots % 4 == 0) { Serial.print('.'); }
    delay(SAMPLE_EVERY_MS);
  }
  Serial.println();

  for (uint8_t i = 0; i < NPINS; i++) {
    Serial.printf("  GPIO%u  mean %4u mV   range %4u-%4u mV\n",
                  PINS[i], meanOf(dest[i]), dest[i].lo, dest[i].hi);
  }
}

static void waitForEnter(const char *prompt) {
  Serial.printf("\n>>> %s\n>>> Then press Enter here.\n", prompt);
  while (Serial.available()) Serial.read();          // flush anything stale
  for (;;) {
    if (Serial.available()) {
      int c = Serial.read();
      if (c == '\n' || c == '\r') break;
    }
    delay(20);
  }
  while (Serial.available()) Serial.read();          // eat the rest of the line
}

// ---------------------------------------------------------------------
static void verdict() {
  uint16_t expected = BAT_NOMINAL_MV / 2;            // a 2:1 divider

  Serial.println("\n=====================================================");
  Serial.println(" GPIO   no cell   with cell    delta   verdict");
  Serial.println("-----------------------------------------------------");

  int8_t found = -1;

  for (uint8_t i = 0; i < NPINS; i++) {
    uint16_t a = meanOf(phaseA[i]);
    uint16_t b = meanOf(phaseB[i]);
    int16_t  d = (int16_t)b - (int16_t)a;

    const char *v;
    if (abs(d) < NOISE_BAND_MV)                 v = "unchanged -> not VBAT";
    else if (abs(d) < DELTA_SIGNIFICANT)        v = "small shift -> doubtful";
    else if (b > 3000)                          v = "!! TOO HIGH, UNPLUG !!";
    else                                        { v = "MOVED -> VBAT candidate"; found = i; }

    Serial.printf(" %4u   %5u mV   %5u mV   %+5d mV   %s\n",
                  PINS[i], a, b, d, v);
  }

  Serial.println("-----------------------------------------------------");
  Serial.printf(" A 2:1 divider on a %u mV cell reads ~%u mV.\n",
                BAT_NOMINAL_MV, expected);

  if (found >= 0) {
    uint16_t b = meanOf(phaseB[found]);
    Serial.printf("\n GPIO%u is your VBAT pin.\n", PINS[found]);
    Serial.printf(" Implied divider ratio: %u.%02u : 1\n",
                  (BAT_NOMINAL_MV * 100 / b) / 100,
                  (BAT_NOMINAL_MV * 100 / b) % 100);
    Serial.println(" Set BAT_ADC_PIN and DIVIDER_X100 in beacon.ino,");
    Serial.println(" then confirm against a multimeter on the cell.");
  } else {
    Serial.println("\n No pin moved when the cell was connected.");
    Serial.println(" This board has NO on-board VBAT divider. Wire one:");
    Serial.println();
    Serial.println("   switched battery + -- R1 100k --+-- R2 100k -- GND");
    Serial.println("                                   |");
    Serial.println("                                   +-- C1 100nF - GND");
    Serial.println("                                   |");
    Serial.println("                                   +-- GPIO3 or GPIO4");
    Serial.println();
    Serial.println(" Tap R1 AFTER the switch, or it drains the cell.");
    Serial.println(" Keep C1 physically against the board.");
  }
  Serial.println("=====================================================");
}
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

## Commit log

2026-08-16 Functional Beacon and appropriate case
    Enclosure STL models for 3D printing.
    Beacon code with a choice of boards (C3 pico, M5 Nano C6, Generic)
    READMEs updated
    [body.stl, enclosure.scad, lid-nfc-inside.stl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]
2026-08-16 STL and GCODe for lid and body
    [body.stl, lid-nfc-inside.stl, lid.stl]
2026-08-18 Shutdown flat added
    If battery reaches below 3.2v, send beacon to deep sleep to avoid severe damage to battery.
    Few bug fixes.
    [beacon.ino]
2026-08-21 Beacon code + device
2026-08-21 Battery discharge documented
